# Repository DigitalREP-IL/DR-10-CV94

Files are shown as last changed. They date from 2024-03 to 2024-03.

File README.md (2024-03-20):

This is a tile-able design to drive a 25-pixel matrix of Cree CV-94 LED clusters. These are typically used in outdoor and longer distance applications, so the visual separation of the R,G, and B LEDs is not noticeable. The board is laid out such that four can be clustered together and maintain a regular pixel spacing. The onboard driver is I2C addressable but not pre-programmed so an external controller is necessary. Example code for the Arduino environment (easily portable to other frameworks) on a Raspberry Pi Pico (RP2040) is available.

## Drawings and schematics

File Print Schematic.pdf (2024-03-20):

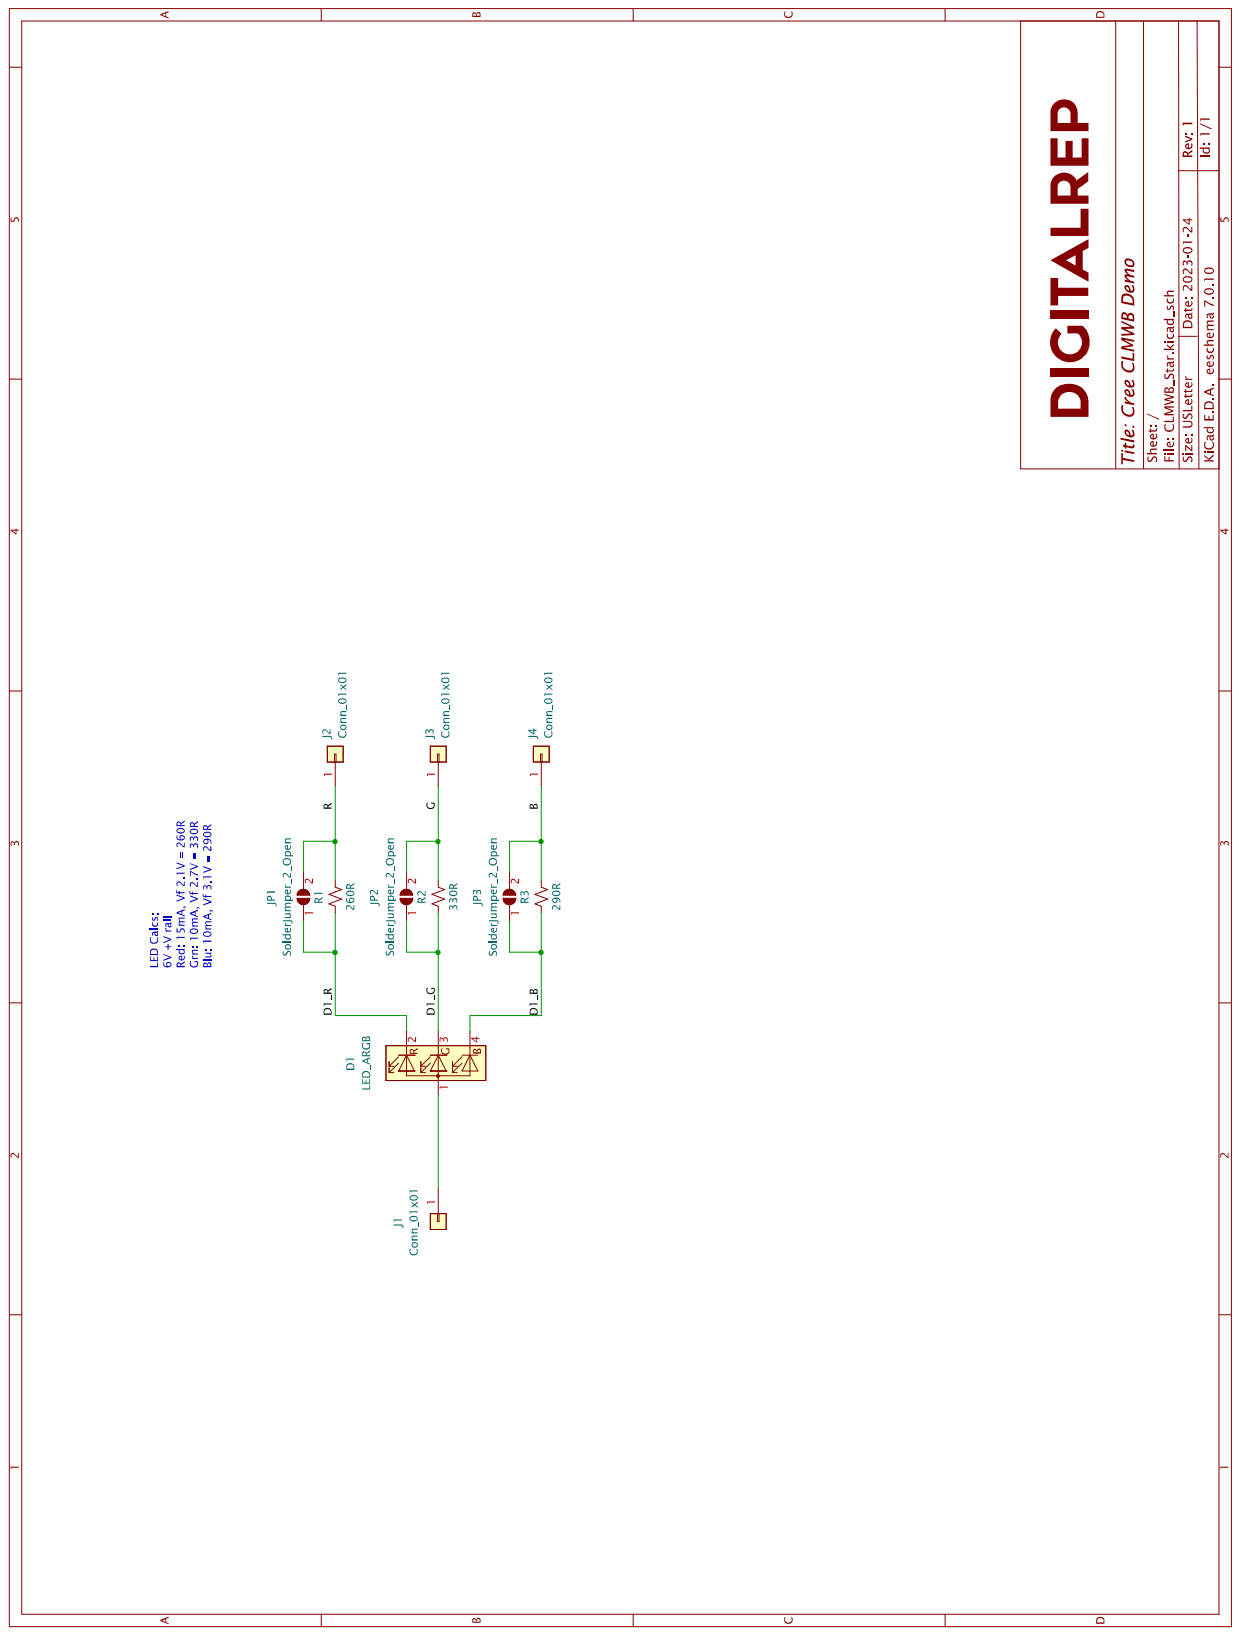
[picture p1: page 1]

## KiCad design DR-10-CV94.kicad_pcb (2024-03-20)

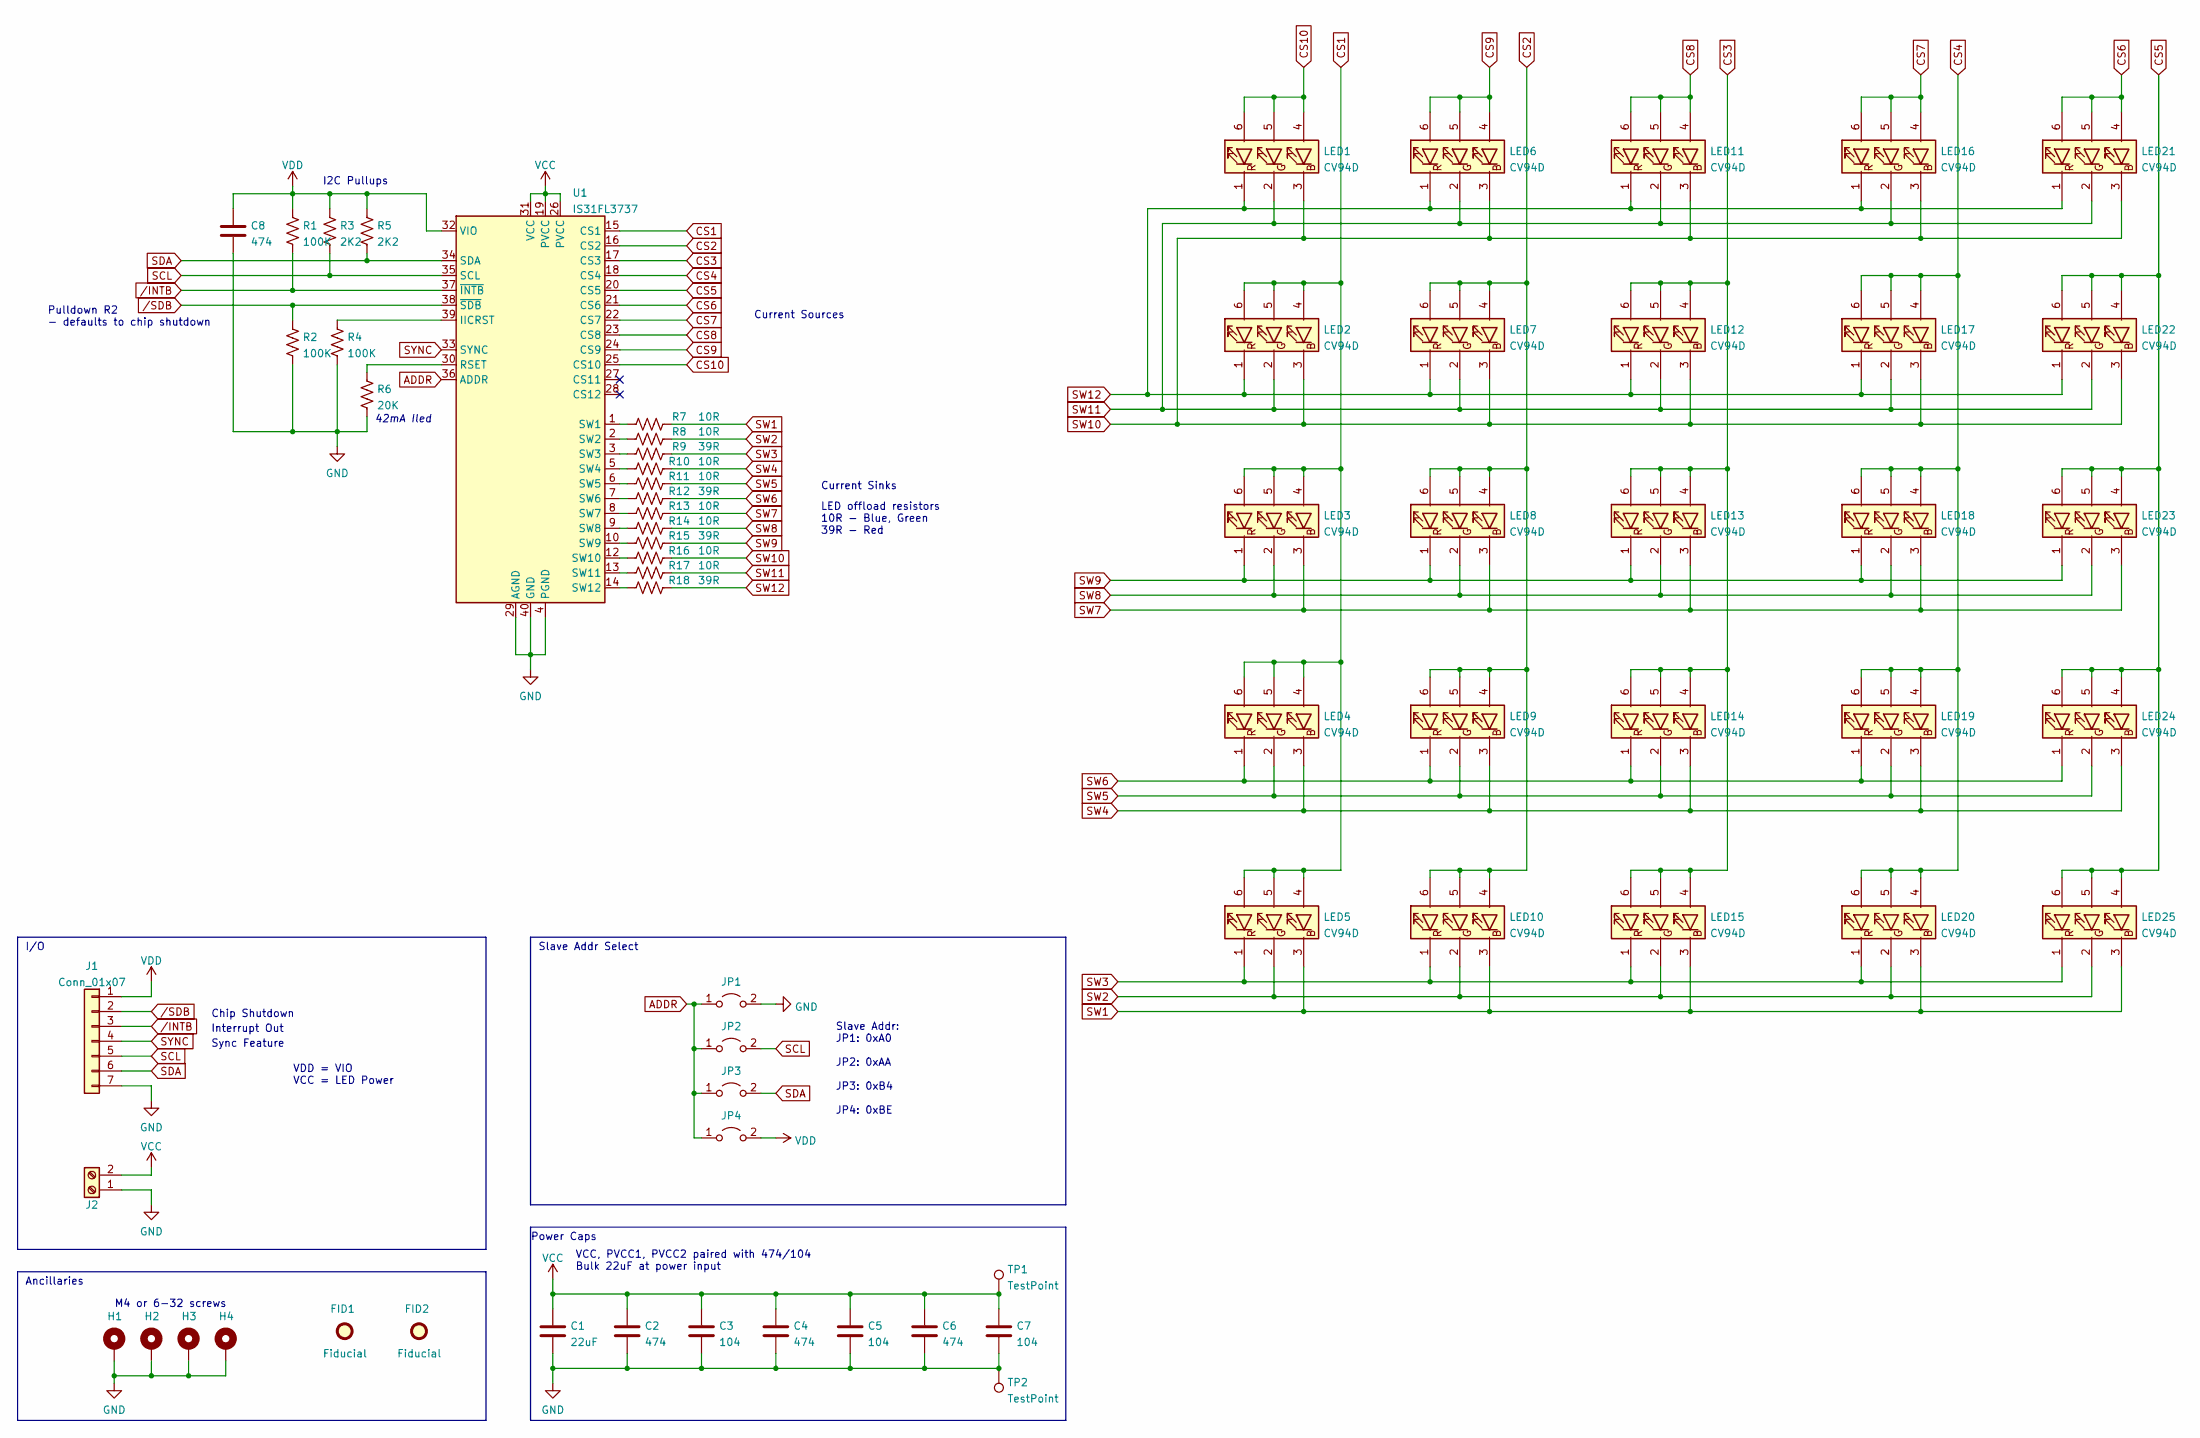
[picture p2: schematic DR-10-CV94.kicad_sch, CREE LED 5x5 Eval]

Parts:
C1: 22uF; CP_Elec_4x4.5
C2, C4, C6, C8: 474; C_0805_2012Metric
C3, C5, C7: 104; C_0805_2012Metric
FID1, FID2: Fiducial; Fiducial_0.5mm_Mask1mm
H1, H2, H3, H4: MountingHole_Pad; MountingHole_4.3mm_M4_ISO7380_Pad_TopBottom
J1: Conn_01x07; PinHeader_1x07_P2.54mm_Horizontal
J2: Screw_Terminal_01x02; TerminalBlock_Phoenix_MPT-0,5-2-2.54_1x02_P2.54mm_Horizontal
JP1, JP2, JP3, JP4: Jumper_2_Open; PinHeader_1x02_P2.54mm_Vertical
LED1, LED2, LED3, LED4, LED5, LED6, LED7, LED8, LED9, LED10, LED11, LED12, LED13, LED14, LED15, LED16, LED17, LED18, LED19, LED20, LED21, LED22, LED23, LED24, LED25: CV94D; LED_CREE_PLCC6_3n1
R1, R2, R4: 100K; R_0603_1608Metric
R3, R5: 2K2; R_0603_1608Metric
R6: 20K; R_0805_2012Metric
R7, R8, R10, R11, R13, R14, R16, R17: 10R; R_0603_1608Metric
R9, R12, R15, R18: 39R; R_0603_1608Metric
TP1, TP2: TestPoint; TestPoint_Pad_D2.5mm
U1: IS31FL3737; QFN-40-1EP_5x5mm_P0.4mm_EP3.8x3.8mm

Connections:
ADDR: JP1.1 (A), JP2.1 (A), JP3.1 (A), JP4.1 (A), U1.36 (ADDR)
CS1: LED2.4 (BA), LED2.5 (GA), LED2.6 (RA), LED3.4 (BA), LED3.5 (GA), LED3.6 (RA), LED4.4 (BA), LED4.5 (GA), LED4.6 (RA), LED5.4 (BA), LED5.5 (GA), LED5.6 (RA), U1.15 (CS1)
CS2: LED7.4 (BA), LED7.5 (GA), LED7.6 (RA), LED8.4 (BA), LED8.5 (GA), LED8.6 (RA), LED9.4 (BA), LED9.5 (GA), LED9.6 (RA), LED10.4 (BA), LED10.5 (GA), LED10.6 (RA), U1.16 (CS2)
CS3: LED12.4 (BA), LED12.5 (GA), LED12.6 (RA), LED13.4 (BA), LED13.5 (GA), LED13.6 (RA), LED14.4 (BA), LED14.5 (GA), LED14.6 (RA), LED15.4 (BA), LED15.5 (GA), LED15.6 (RA), U1.17 (CS3)
CS4: LED17.4 (BA), LED17.5 (GA), LED17.6 (RA), LED18.4 (BA), LED18.5 (GA), LED18.6 (RA), LED19.4 (BA), LED19.5 (GA), LED19.6 (RA), LED20.4 (BA), LED20.5 (GA), LED20.6 (RA), U1.18 (CS4)
CS5: LED22.4 (BA), LED22.5 (GA), LED22.6 (RA), LED23.4 (BA), LED23.5 (GA), LED23.6 (RA), LED24.4 (BA), LED24.5 (GA), LED24.6 (RA), LED25.4 (BA), LED25.5 (GA), LED25.6 (RA), U1.20 (CS5)
CS6: LED21.4 (BA), LED21.5 (GA), LED21.6 (RA), U1.21 (CS6)
CS7: LED16.4 (BA), LED16.5 (GA), LED16.6 (RA), U1.22 (CS7)
CS8: LED11.4 (BA), LED11.5 (GA), LED11.6 (RA), U1.23 (CS8)
CS9: LED6.4 (BA), LED6.5 (GA), LED6.6 (RA), U1.24 (CS9)
CS10: LED1.4 (BA), LED1.5 (GA), LED1.6 (RA), U1.25 (CS10)
GND: C1.2, C2.2, C3.2, C4.2, C5.2, C6.2, C7.2, C8.2, H1.1, H2.1, H3.1, H4.1, J1.7, J2.1, JP1.2 (B), R2.2, R4.2, R6.2, TP2.1, U1.4 (PGND), U1.11 (PGND), U1.29 (AGND), U1.40 (GND), U1.41 (GND)
unnamed: R4.1, U1.39 (IICRST)
unnamed: R6.1, U1.30 (RSET)
unnamed: R7.1, U1.1 (SW1)
unnamed: R8.1, U1.2 (SW2)
unnamed: R9.1, U1.3 (SW3)
unnamed: R10.1, U1.5 (SW4)
unnamed: R11.1, U1.6 (SW5)
unnamed: R12.1, U1.7 (SW6)
unnamed: R13.1, U1.8 (SW7)
unnamed: R14.1, U1.9 (SW8)
unnamed: R15.1, U1.10 (SW9)
unnamed: R16.1, U1.12 (SW10)
unnamed: R17.1, U1.13 (SW11)
unnamed: R18.1, U1.14 (SW12)
SCL: J1.5, JP2.2 (B), R3.2, U1.35 (SCL)
SDA: J1.6, JP3.2 (B), R5.2, U1.34 (SDA)
SW1: LED5.3 (BK), LED10.3 (BK), LED15.3 (BK), LED20.3 (BK), LED25.3 (BK), R7.2
SW2: LED5.2 (GK), LED10.2 (GK), LED15.2 (GK), LED20.2 (GK), LED25.2 (GK), R8.2
SW3: LED5.1 (RK), LED10.1 (RK), LED15.1 (RK), LED20.1 (RK), LED25.1 (RK), R9.2
SW4: LED4.3 (BK), LED9.3 (BK), LED14.3 (BK), LED19.3 (BK), LED24.3 (BK), R10.2
SW5: LED4.2 (GK), LED9.2 (GK), LED14.2 (GK), LED19.2 (GK), LED24.2 (GK), R11.2
SW6: LED4.1 (RK), LED9.1 (RK), LED14.1 (RK), LED19.1 (RK), LED24.1 (RK), R12.2
SW7: LED3.3 (BK), LED8.3 (BK), LED13.3 (BK), LED18.3 (BK), LED23.3 (BK), R13.2
SW8: LED3.2 (GK), LED8.2 (GK), LED13.2 (GK), LED18.2 (GK), LED23.2 (GK), R14.2
SW9: LED3.1 (RK), LED8.1 (RK), LED13.1 (RK), LED18.1 (RK), LED23.1 (RK), R15.2
SW10: LED1.3 (BK), LED2.3 (BK), LED6.3 (BK), LED7.3 (BK), LED11.3 (BK), LED12.3 (BK), LED16.3 (BK), LED17.3 (BK), LED21.3 (BK), LED22.3 (BK), R16.2
SW11: LED1.2 (GK), LED2.2 (GK), LED6.2 (GK), LED7.2 (GK), LED11.2 (GK), LED12.2 (GK), LED16.2 (GK), LED17.2 (GK), LED21.2 (GK), LED22.2 (GK), R17.2
SW12: LED1.1 (RK), LED2.1 (RK), LED6.1 (RK), LED7.1 (RK), LED11.1 (RK), LED12.1 (RK), LED16.1 (RK), LED17.1 (RK), LED21.1 (RK), LED22.1 (RK), R18.2
SYNC: J1.4, U1.33 (SYNC)
VCC: C1.1, C2.1, C3.1, C4.1, C5.1, C6.1, C7.1, J2.2, TP1.1, U1.19 (PVCC), U1.26 (PVCC), U1.31 (VCC)
VDD: C8.1, J1.1, JP4.2 (B), R1.1, R3.1, R5.1, U1.32 (VIO)
/INTB: J1.3, R1.2, U1.37 (~INTB)
/SDB: J1.2, R2.1, U1.38 (~SDB)

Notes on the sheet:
LED offload resistors 10R - Blue, Green 39R - Red
Slave Addr: JP1: 0xA0 JP2: 0xAA JP3: 0xB4 JP4: 0xBE
Sync Feature
Interrupt Out
I/O
Power Caps
Pulldown R2 - defaults to chip shutdown
Ancillaries
Current Sinks
42mA Iled
VCC, PVCC1, PVCC2 paired with 474/104 Bulk 22uF at power input
M4 or 6-32 screws
I2C Pullups
Current Sources
Chip Shutdown
VDD = VIO VCC = LED Power
Slave Addr Select

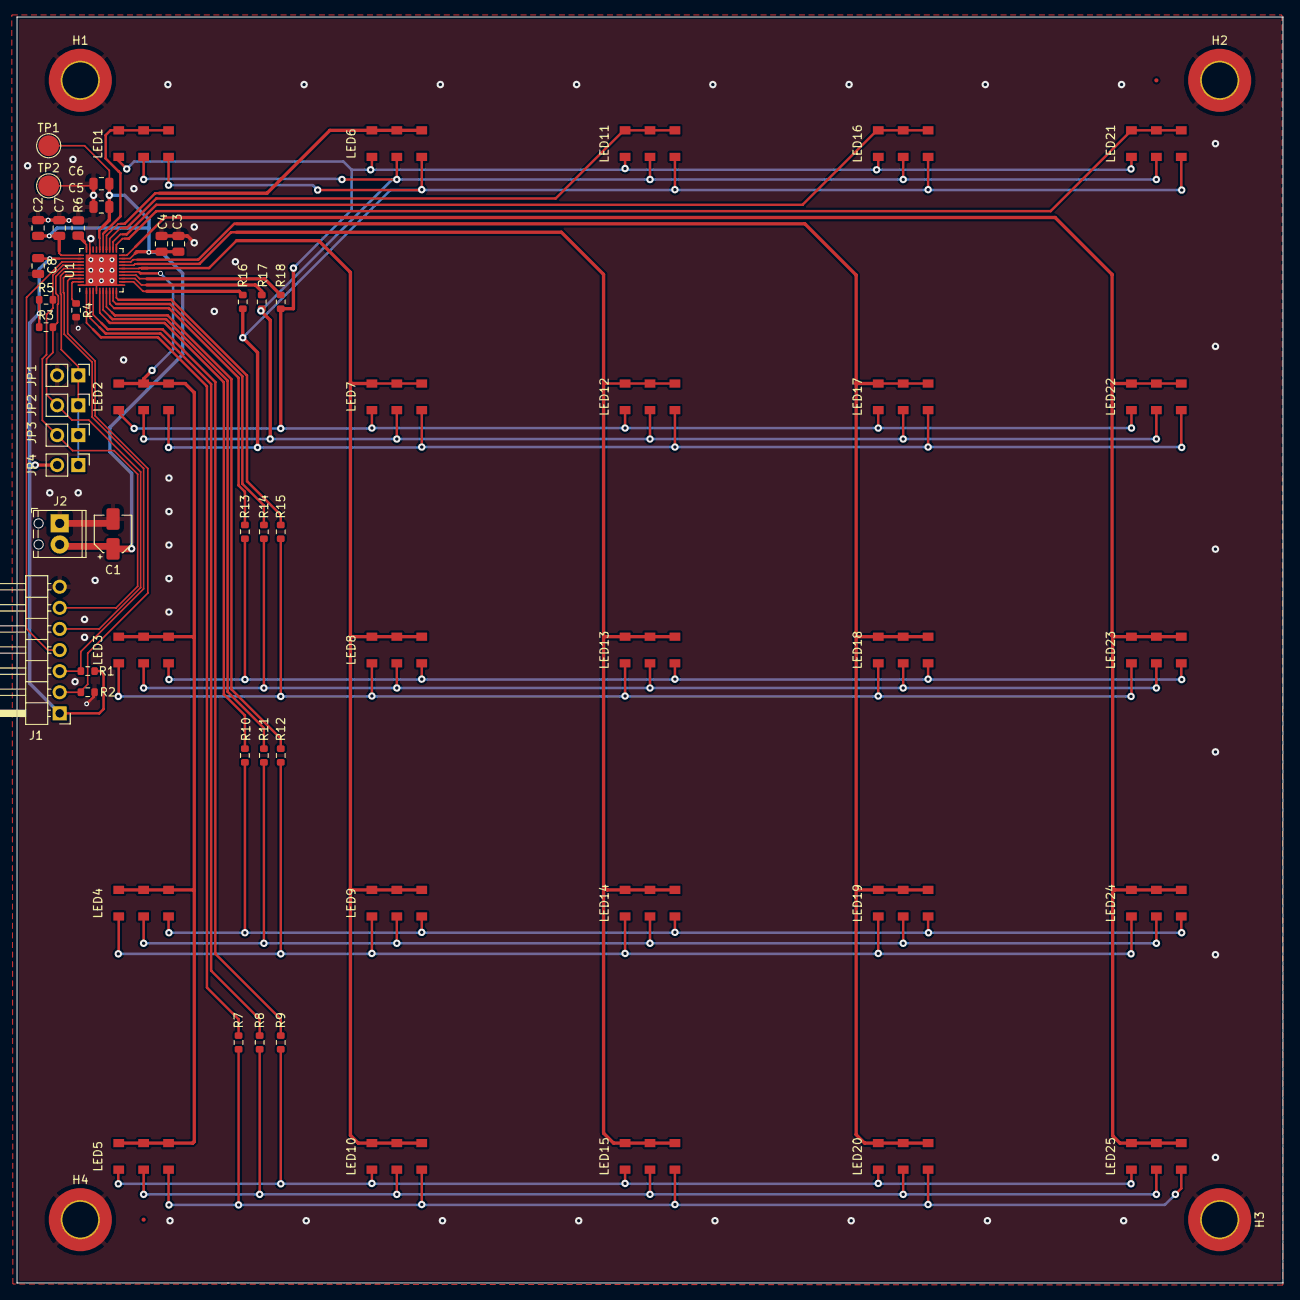
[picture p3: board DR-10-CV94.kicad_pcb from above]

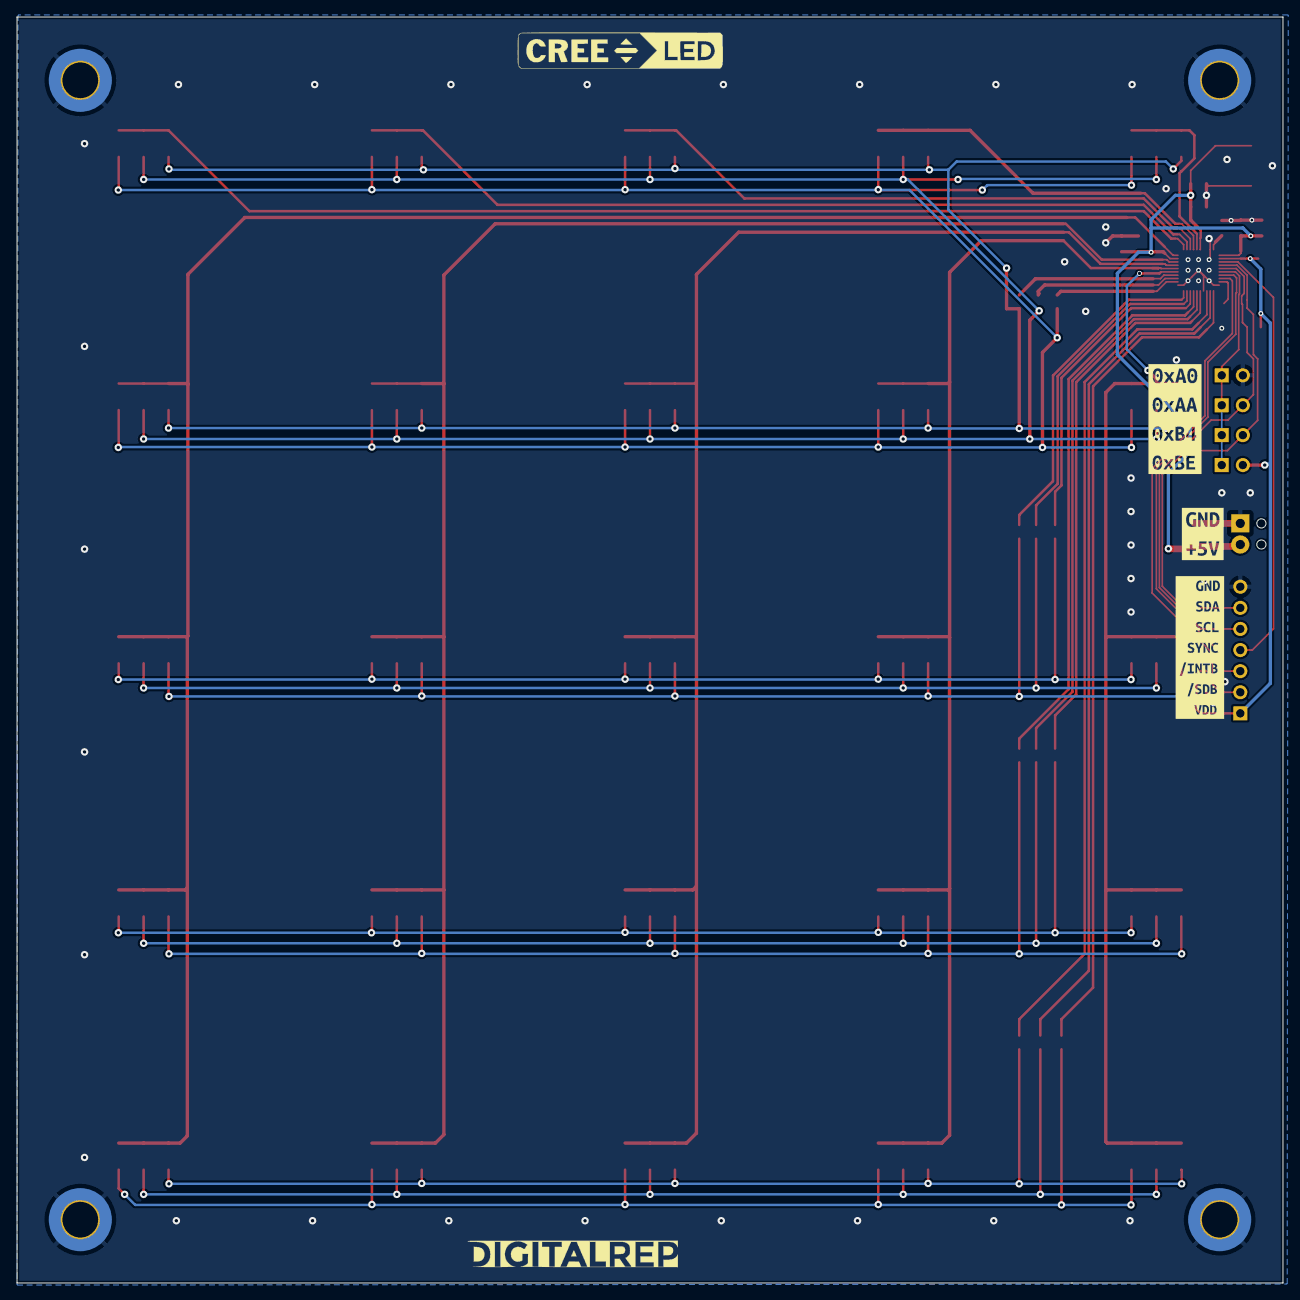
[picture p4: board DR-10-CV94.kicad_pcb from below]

Board: 2 copper layers, 152.4 x 152.4 mm, 69 parts (3 on the bottom side), 45 nets.

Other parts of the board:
kibuzzard-63458A05: G***; kibuzzard-63458A05
kibuzzard-634588F2: G***; kibuzzard-634588F2
kibuzzard-6345892A: G***; kibuzzard-6345892A

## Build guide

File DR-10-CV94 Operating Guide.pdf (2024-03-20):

2024-03-13 | 1

# DR-10-CV94 Operating Guide

### DESIGN GOALS

This is a tile-able design to drive a 25-pixel matrix of Cree CV-94 LED clusters. These are typically used in outdoor and longer distance applications, so the visual separation of the R,G, and B LEDs is not noticeable. The board is laid out such that four can be clustered together and maintain a regular pixel spacing. The onboard driver is I2C addressable but not pre-programmed so an external controller is necessary. Example code for the Arduino environment (easily portable to other frameworks) on a Raspberry Pi Pico (RP2040) is available.

### HOOKUP

LED power is supplied on the terminal block (J2). This is a 4.5-5.5V input.

Controller power is supplied on J1, as marked. This is the I/O voltage and should be supplied by the external controller (ie, the Pi Pico PCB).

Jumpers JP1-JP4 configure the I2C address (8-bit, unshifted) of each board:

Jumper | I2C Address
JP1 | 0xA0
JP2 | 0xAA
JP3 | 0xB4
JP4 | 0xBE

### OPERATION

The external controller must be programmed initially; the instructions below are for our demo firmware.

### 1. power to matrix board first, 5V nominal (demo is jumpered to USB power) 2. plug in rp2040 board to USB 3. there is a5 second delay to allow host OS to enumerate USB before starting the array 4. a COM port should show up

5. solid green LED on rp2040, flashes if I2C doesn’t configure the board (check connections)

### 6. led matrix should be all-on

7. Run terminal emulator (puTTY, Tera Term, etc) at 115,200 baud 8,N,1 connected to the serial port assigned in step 3a

### COMMAND INTERFACE

All commands are three characters followed by a value, then press [enter]:

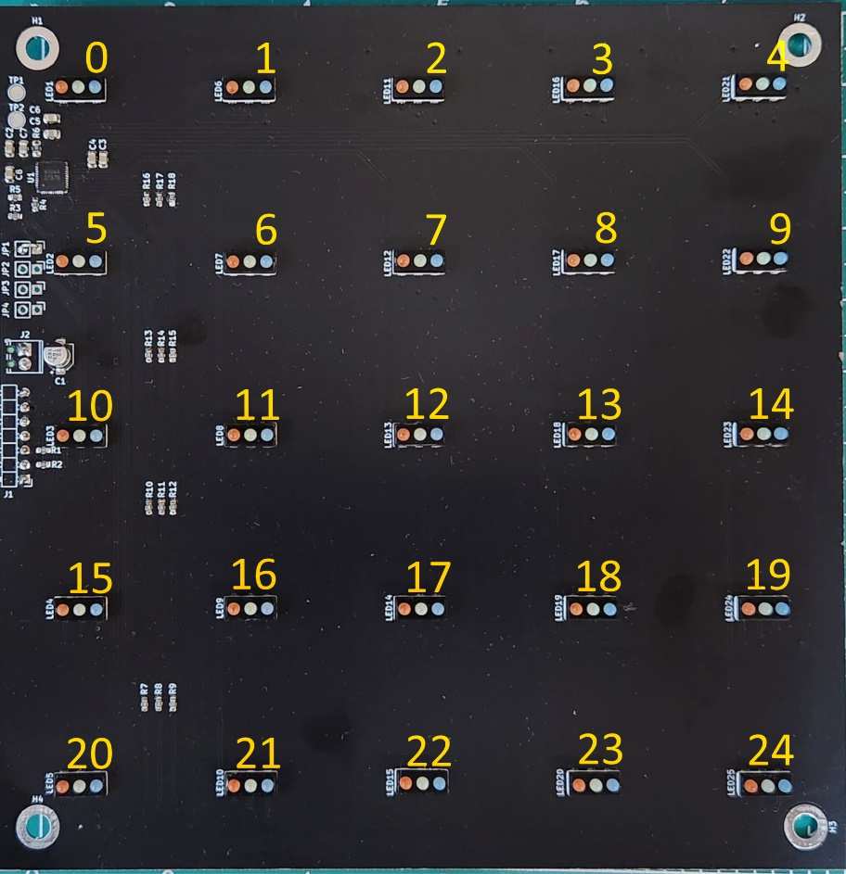
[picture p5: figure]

2024-03-13 | 2
- cur nnn – set global current, scale from 0-255
- red nnn – set all red pixels, PWM value 0-255
- grn nnn – set all green pixels, PWM value 0-255
- blu nnn – set all blue pixels, PWM value 0-255
- pix nn rrr ggg bbb – set a pixel (0-24) at RGB values given
- rbw n – set rainbow mode, 0 (off) or 1 (on)

Successful commands will echo back to the terminal, unknown commands will error.

Pixels numbered as shown:

### FIRMWARE NOTES

The IS31FL3737.c/.h API is lightly edited from Lumissil’s example code. I2C transactions via this API are wrapped around the Arduino Wire library in I2C.c/.h. Porting to another framework should therefore be started in the I2C interface.

IS31FL3737RES.hpp contains a lookup table to map the IS31FL3737 PWM registers to the numbered pixels. In an effort to keep the PCB fanout simple and the stackup to 2 layers, pins were chosen for the most convenient layout. Thus, the pixel mapping is not fully sequential with the PWM registers.

2024-03-13 | 3

Some example usage is included in the application code in IS31FL3737_Controller.ino. Methods to change individual pixels and entire buffers are shown. Low framerate video may be possible using the buffer writes, but is still somewhat limited by the 400kHz I2C interface.

A simple “rainbow” function is included to show a constant brightness color sweep. An indexed value through the HSV color space is converted to RGB values and written to the pixel buffer.
